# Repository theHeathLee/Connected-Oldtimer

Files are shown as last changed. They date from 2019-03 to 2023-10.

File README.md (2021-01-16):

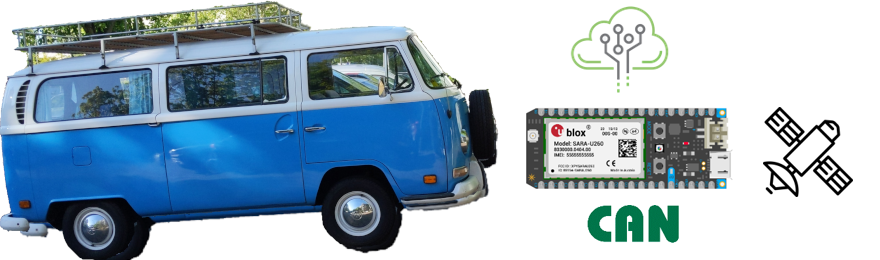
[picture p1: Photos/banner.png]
Connected oldtimer banner


# Connected-Oldtimer

The aim of this project to modernize my old Volkswagen T2 by adding sensors everywhere and make it part of the internet of things. This project is not vehicle specific and can be implimented in any pre OBD vehicle.

The goal here is first to make remote monitoring possible. Motion sensing for anti theft will be implemented as the vehicle does a lot of sitting. (my bicycle has x4 the ammount of kms per year on it as the bus). Additionaly the ability to remotely view levels (battery charge, fuel level etc..)

Alongside remote monitoring I have implmented an HMI using a 3.5" Display that fits in the dash area originally inteded for the RPM guage. This display shows the instantanious data such as speed, RPM, and Temperature.

A low speed CAN network is set up throughout the vehicle to easily add extra sensors.

Disclaimer: Still in the __developement phase__. V1 hardware has been created and software is still in heavy developement.

### Software used:
- Visual Studio Code w/ [Particle Workbench Extentsion](https://marketplace.visualstudio.com/items?itemName=particle.particle-vscode-pack)🤘
- Particle [Cloud](https://www.particle.io/device-cloud/) 
- [BusMaster](http://rbei-etas.github.io/busmaster/)

### Things implemented:

- 3G Connectivity and vehicle to [cloud](https://www.particle.io/device-cloud/) data transfer   
- Gps velocity and location tracking and display  
- CAN Bus Sensor Data
- Movement Sensor 
- 3D Printed Display mount ([Thingiverse](https://www.thingiverse.com/thing:4713912))

### Parts List:

- [Particle Electron](https://www.particle.io/cellular/)
- [Nextion 3.5" Display](https://www.itead.cc/nextion-nx4832t035.html)
- [Adafruit Ultimage GPS](https://www.adafruit.com/product/746)
- [Adafruit I2C FRAM](https://www.adafruit.com/product/1895)
- [Shock Sensor SW-420](https://components101.com/sensors/sw-420-vibration-sensor-module)
- [CAN Bus Tranceiver Module (TJA1051)](https://www.nxp.com/products/analog/interfaces/in-vehicle-network/can-transceiver-and-controllers/high-speed-can-transceiver:TJA1051)
- [CAN Bus Cable](https://www.conrad.de/de/p/busleitung-unitronic-bus-2-x-2-x-0-22-mm-violett-lapp-2170261-meterware-604030.html)
- PCB From this Repo
- [~~Fuel Flow Meter~~](https://www.conrad.com/p/bt-bio-tech-fch-m-pom-lc-ad-6-mm-low-flow-flowmeter-non-corrosive-liquids-water-diesel-oil-150392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)

# End Product

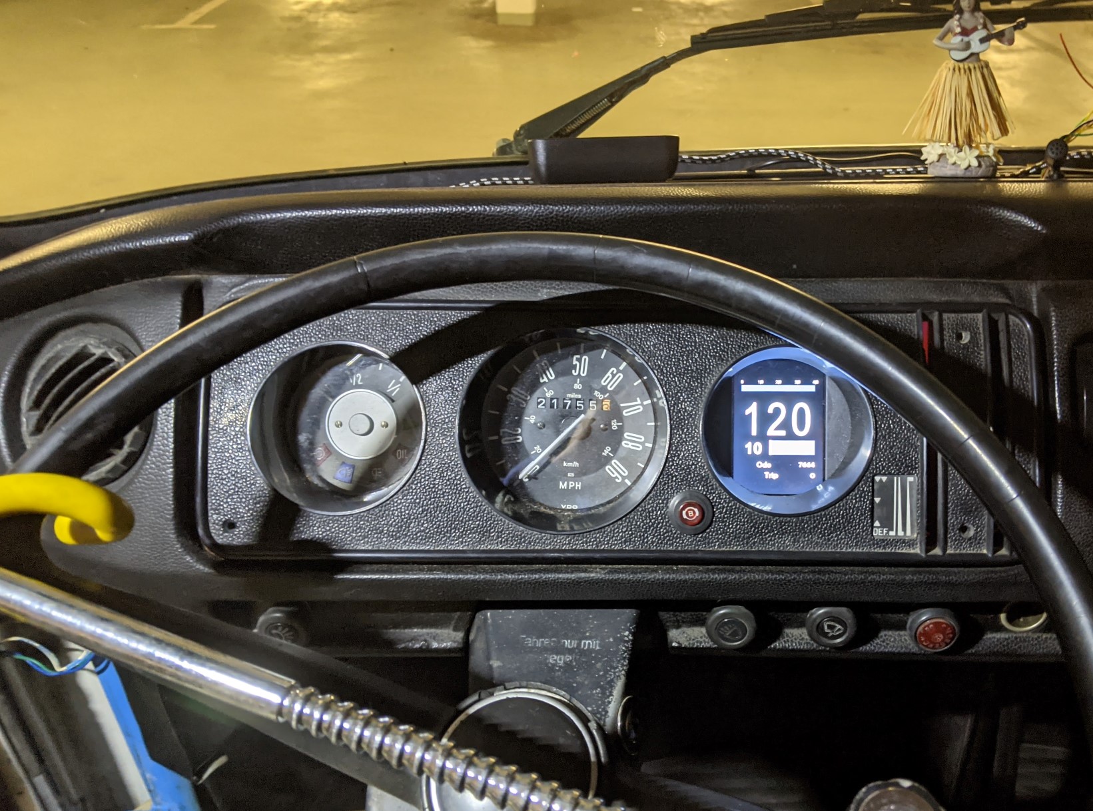
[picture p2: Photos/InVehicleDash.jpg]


# Hardware

[BOM Viewer](https://htmlpreview.github.io/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)

### Schematic

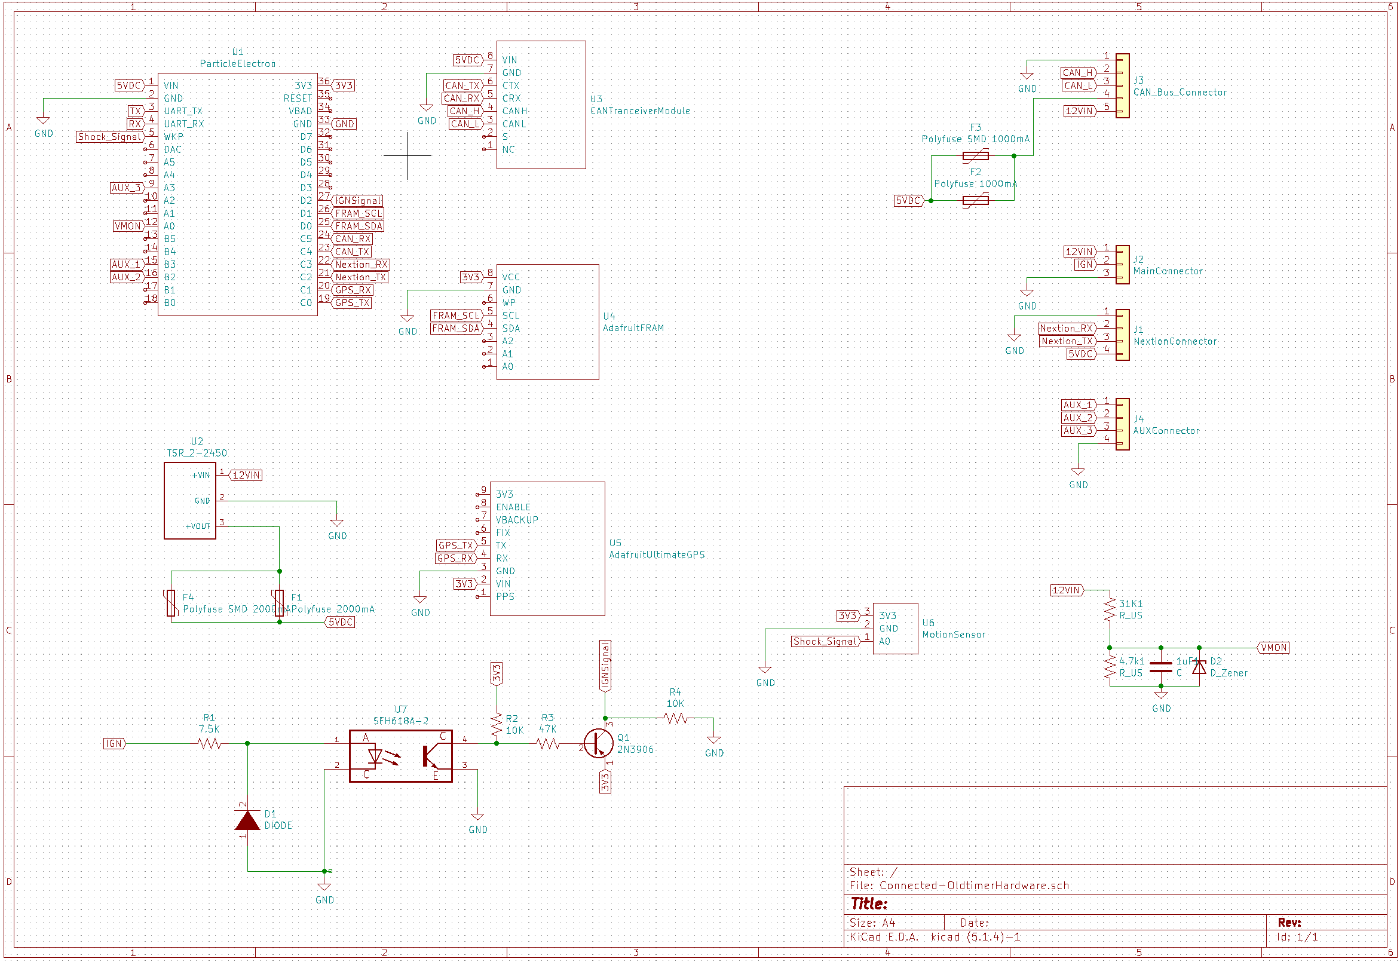
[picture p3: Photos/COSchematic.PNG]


### PCB

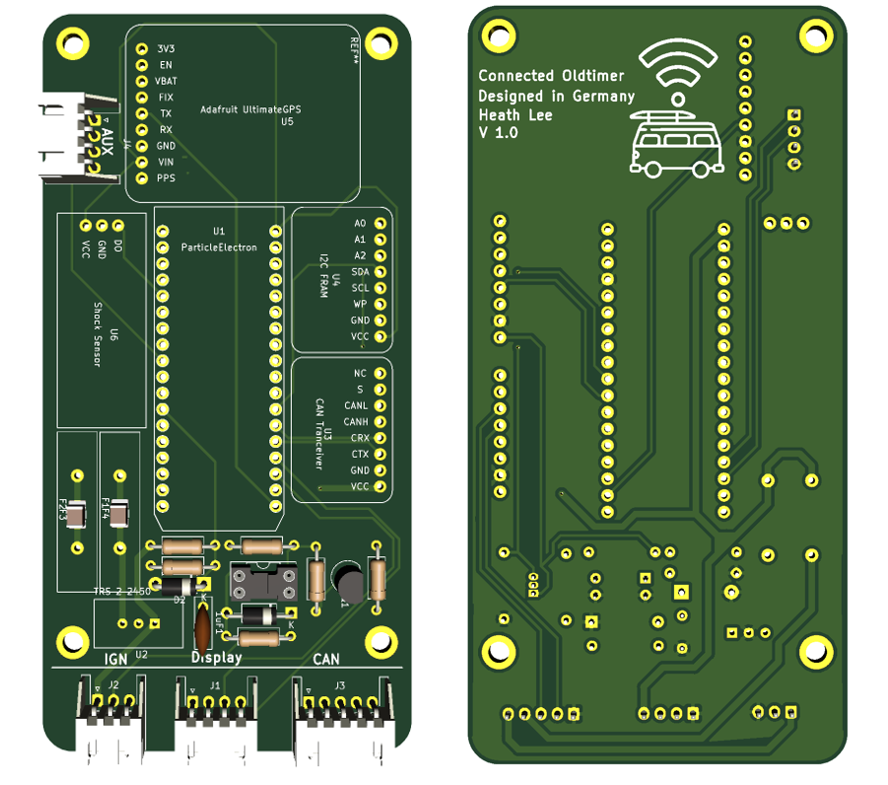
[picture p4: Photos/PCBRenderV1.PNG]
pcb


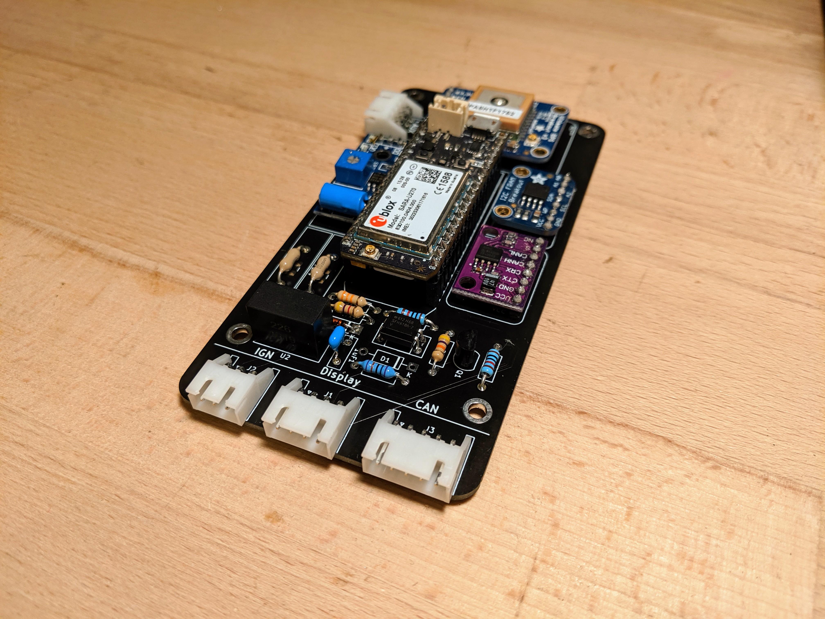
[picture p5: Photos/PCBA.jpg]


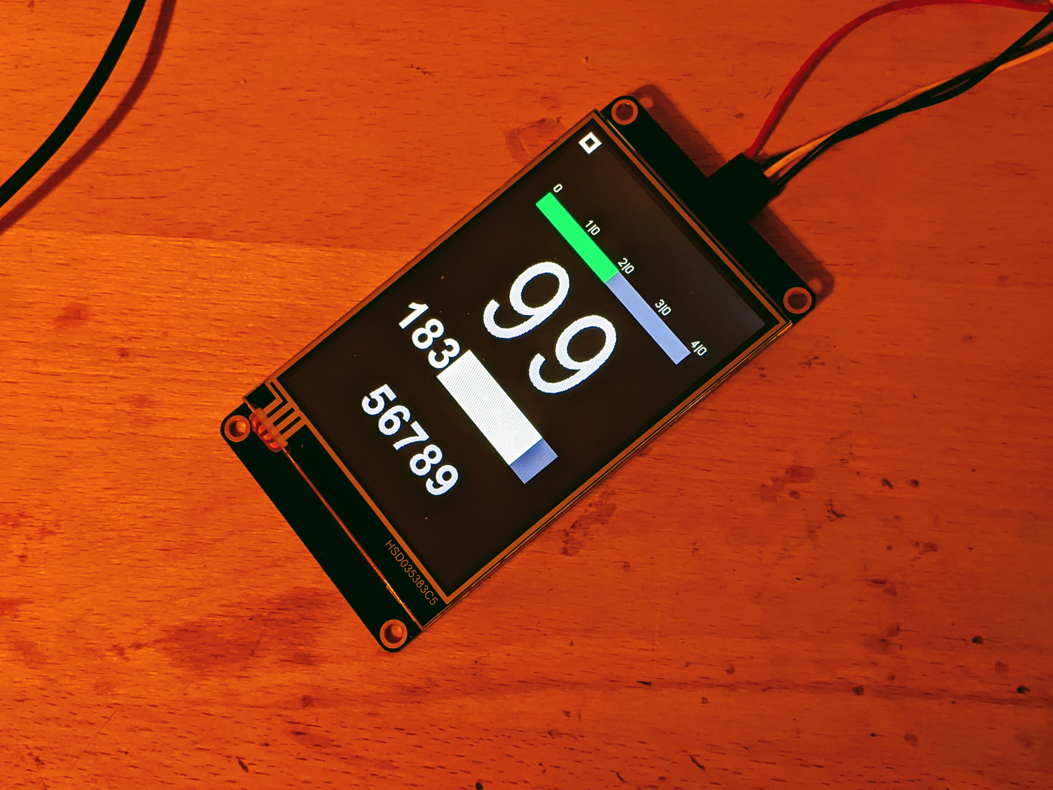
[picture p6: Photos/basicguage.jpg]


## 3D Printed Bracket

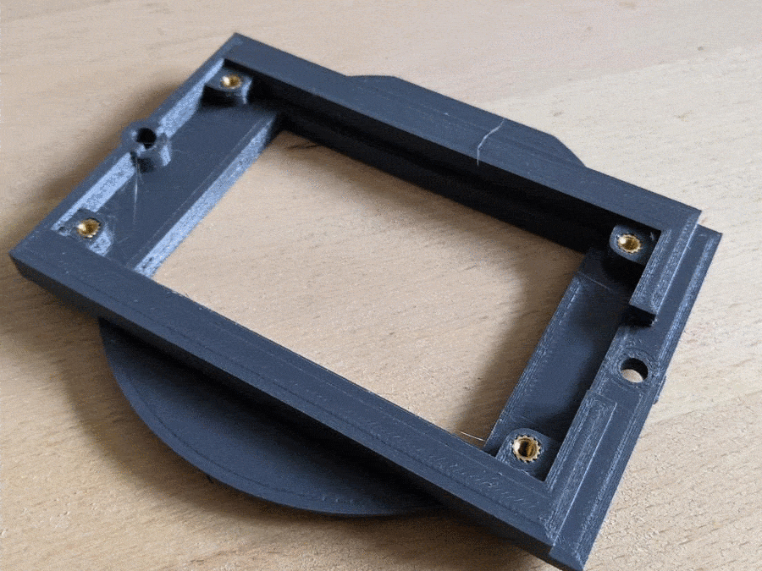
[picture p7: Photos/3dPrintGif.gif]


Art Credits:
[Freepik](https://www.flaticon.com/authors/freepik)

## CAN Matrix

| Value | ID |DLC | Byte Pos.|
| --- |:-----:|----:| --:|
| Temp (C) | 0x100 | 8 |0 |
| RPM | 0x200 | 8 |0, 1|
| Fuel Level | 0x300 | 8 |0 |
| Fuel Flow | 0x400 | 8 |0 |

## Nextion Component Values

| Component  | Value |
| --- |:-----:|
Speed (Kmh) | n0
Odometer (Km) | n1
Trip Counter (Km) | n3
CHT (C) | n2
RPM | va0

# References

## GPS

### NMEA Simulation
[SatGen](https://www.labsat.co.uk/index.php/de/free-gps-nmea-simulator-software) Windows software form LabSat used for playing NMEA files over virtual coms

[NMEAGen](https://nmeagen.org/) browser application for generating custom NMEA files

To create a GPS simulation, first create an NMEA file in NMEAGen. after generating a .nmea file, change the file extension to .txt. The file can now be played in the Serial Output tab of SatGen.

Any USB to TTL coverter can be connected to ports C0 & C1 (Serial5) of the Electron.

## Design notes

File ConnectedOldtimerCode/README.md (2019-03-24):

# ConnectedOldtimerCode

A Particle project named ConnectedOldtimerCode

## Welcome to your project!

Every new Particle project is composed of 3 important elements that you'll see have been created in your project directory for ConnectedOldtimerCode.

#### ```/src``` folder:  
This is the source folder that contains the firmware files for your project. It should *not* be renamed. 
Anything that is in this folder when you compile your project will be sent to our compile service and compiled into a firmware binary for the Particle device that you have targeted.

If your application contains multiple files, they should all be included in the `src` folder. If your firmware depends on Particle libraries, those dependencies are specified in the `project.properties` file referenced below.

#### ```.ino``` file:
This file is the firmware that will run as the primary application on your Particle device. It contains a `setup()` and `loop()` function, and can be written in Wiring or C/C++. For more information about using the Particle firmware API to create firmware for your Particle device, refer to the [Firmware Reference](https://docs.particle.io/reference/firmware/) section of the Particle documentation.

#### ```project.properties``` file:  
This is the file that specifies the name and version number of the libraries that your project depends on. Dependencies are added automatically to your `project.properties` file when you add a library to a project using the `particle library add` command in the CLI or add a library in the Desktop IDE.

## Adding additional files to your project

#### Projects with multiple sources
If you would like add additional files to your application, they should be added to the `/src` folder. All files in the `/src` folder will be sent to the Particle Cloud to produce a compiled binary.

#### Projects with external libraries
If your project includes a library that has not been registered in the Particle libraries system, you should create a new folder named `/lib/<libraryname>/src` under `/<project dir>` and add the `.h`, `.cpp` & `library.properties` files for your library there. Read the [Firmware Libraries guide](https://docs.particle.io/guide/tools-and-features/libraries/) for more details on how to develop libraries. Note that all contents of the `/lib` folder and subfolders will also be sent to the Cloud for compilation.

## Compiling your project

When you're ready to compile your project, make sure you have the correct Particle device target selected and run `particle compile <platform>` in the CLI or click the Compile button in the Desktop IDE. The following files in your project folder will be sent to the compile service:

- Everything in the `/src` folder, including your `.ino` application file
- The `project.properties` file for your project
- Any libraries stored under `lib/<libraryname>/src`

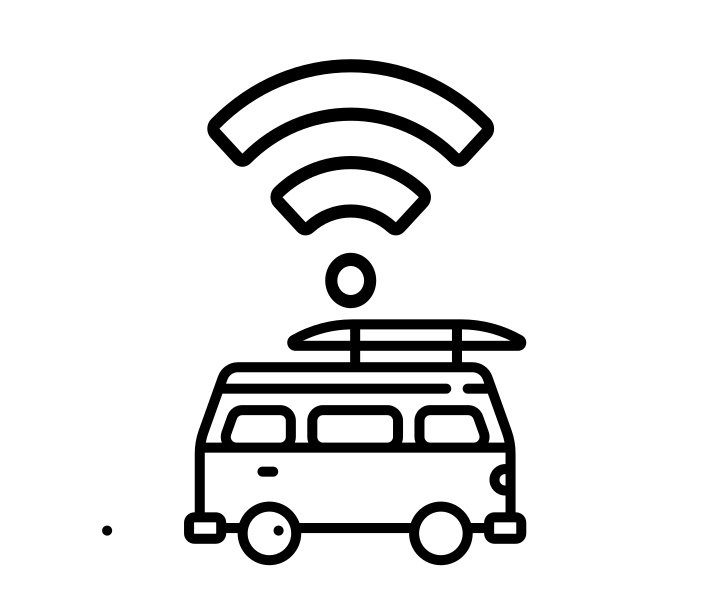
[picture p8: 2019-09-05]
Hardware/Connected-OldtimerHardware/.svg2shenzhen-cache/images/F.Cu_g201.png

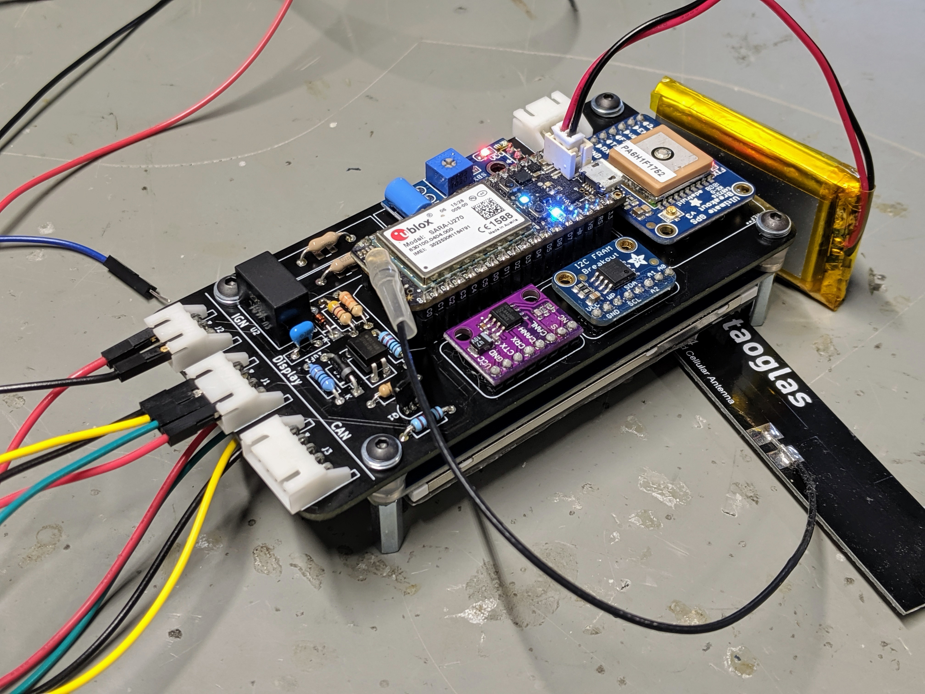
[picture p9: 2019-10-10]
Photos/PCBAWithScreenAndConnectors.jpg

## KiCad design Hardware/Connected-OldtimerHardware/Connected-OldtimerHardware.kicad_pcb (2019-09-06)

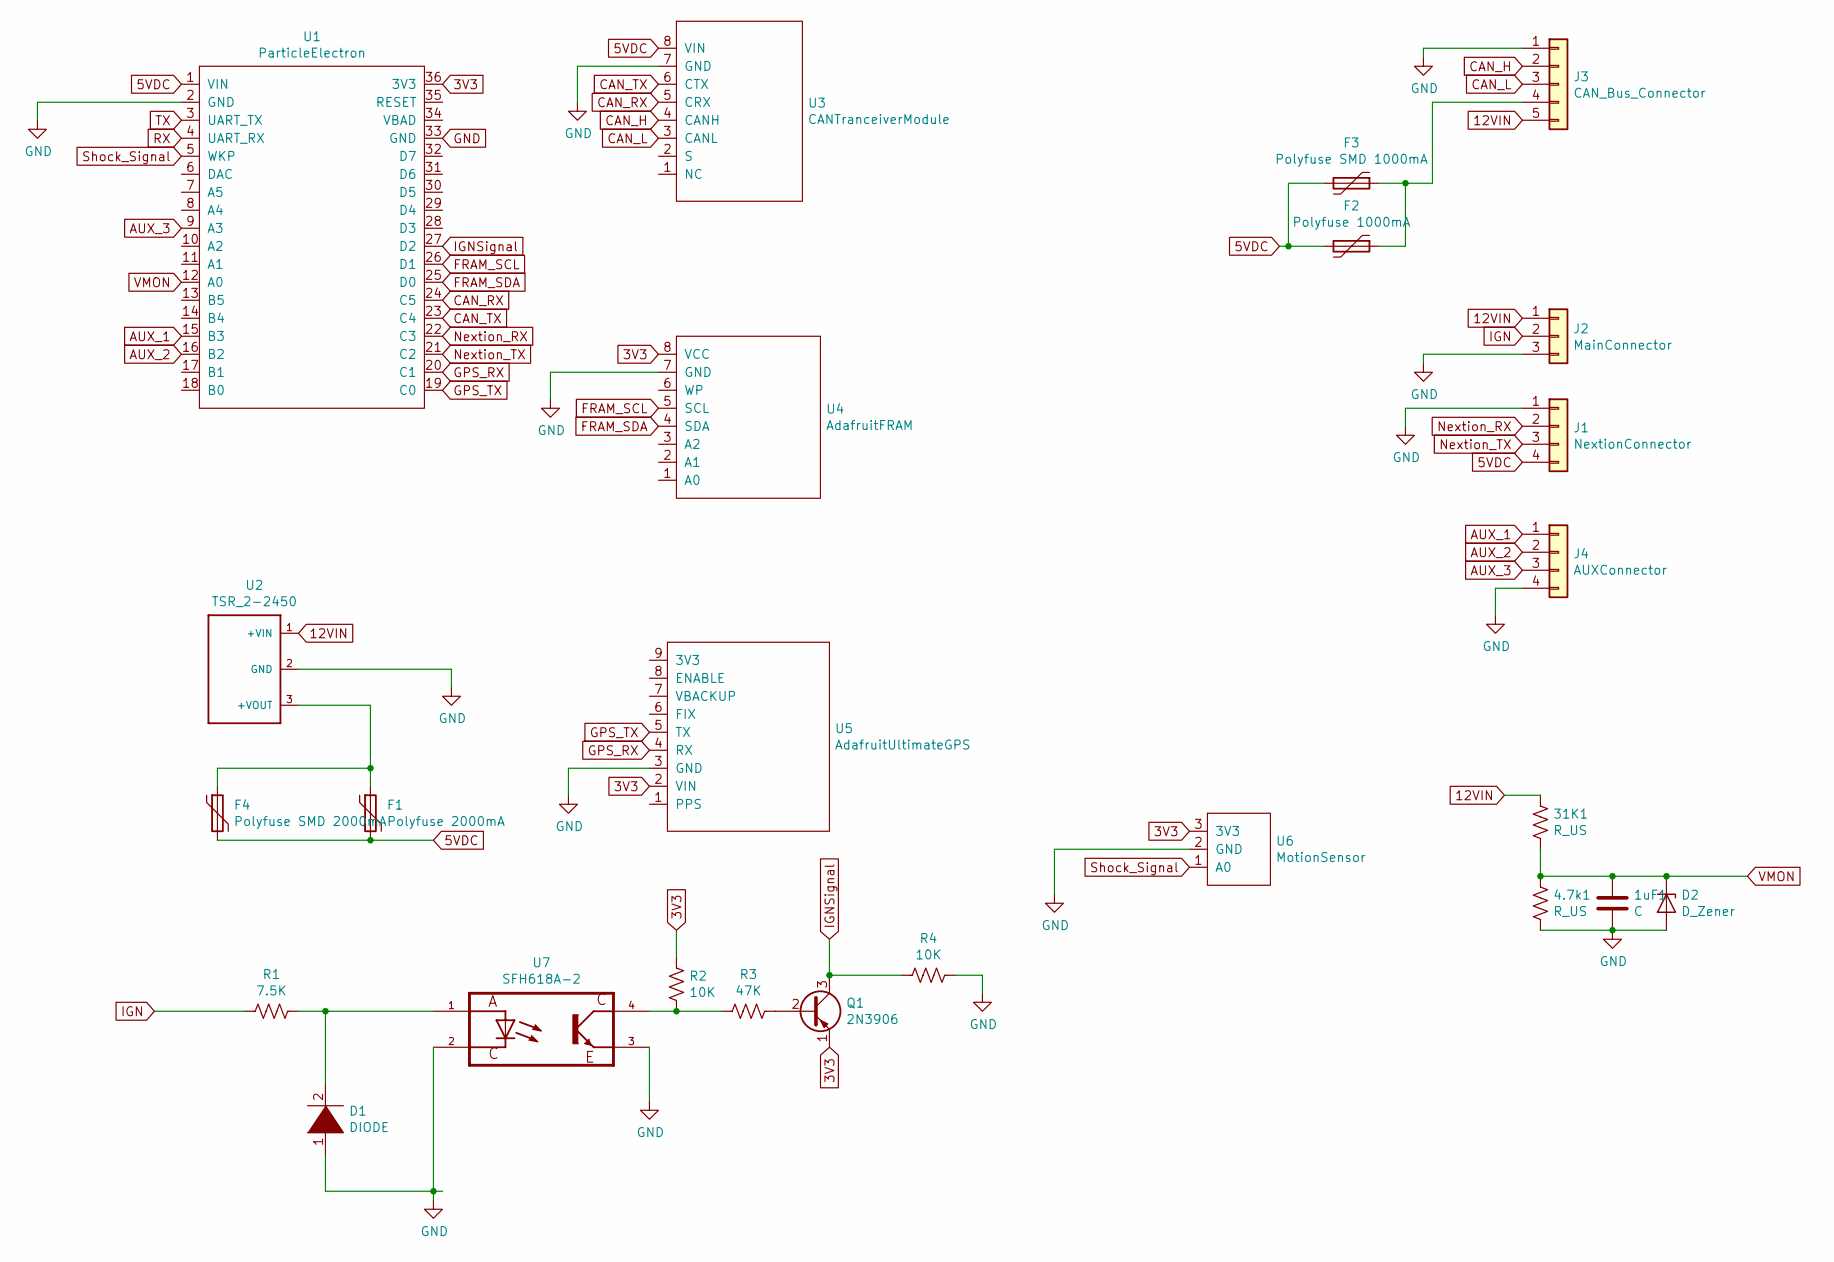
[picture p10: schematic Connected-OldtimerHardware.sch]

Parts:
1uF1: C; C_Disc_D8.0mm_W2.5mm_P5.00mm
4.7k1, 31K1: R_US; R_Axial_DIN0207_L6.3mm_D2.5mm_P10.16mm_Horizontal
D1: DIODE; D_A-405_P10.16mm_Horizontal
D2: D_Zener; D_DO-41_SOD81_P7.62mm_Horizontal
F1: Polyfuse 2000mA; Fuse_Littelfuse-LVR200
F2: Polyfuse 1000mA; Fuse_Littelfuse-LVR200
F3: Polyfuse SMD 1000mA; C_1210_3225Metric_Pad1.42x2.65mm_HandSolder
F4: Polyfuse SMD 2000mA; C_1210_3225Metric_Pad1.42x2.65mm_HandSolder
J1: NextionConnector; JST_XH_S04B-XH-A-1_1x04_P2.50mm_Horizontal
J2: MainConnector; JST_XH_S03B-XH-A-1_1x03_P2.50mm_Horizontal
J3: CAN_Bus_Connector; JST_XH_S05B-XH-A-1_1x05_P2.50mm_Horizontal
J4: AUXConnector; JST_XH_S04B-XH-A-1_1x04_P2.50mm_Horizontal
Q1: 2N3906; TO-92_Inline
R1: 7.5K; R_Axial_DIN0207_L6.3mm_D2.5mm_P10.16mm_Horizontal
R2, R4: 10K; R_Axial_DIN0207_L6.3mm_D2.5mm_P10.16mm_Horizontal
R3: 47K; R_Axial_DIN0207_L6.3mm_D2.5mm_P10.16mm_Horizontal
U1: ParticleElectron; electron
U2: TSR_2-2450; heathsTRS_2_2450
U3: CANTranceiverModule; CAN_Tranceiver_Module
U4: AdafruitFRAM; Adafruit_I2C_FRAM
U5: AdafruitUltimateGPS
U6: MotionSensor; ShockSensor
U7: SFH618A-2; DIP-4_W7.62mm_Socket

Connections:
3V3: Q1.1 (E), R2.1, U1.36 (3V3), U4.8 (VCC), U5.2 (VIN), U6.3 (3V3)
5VDC: F1.2, F2.2, F3.2, F4.2, J1.4, U1.1 (VIN), U3.8 (VIN)
12VIN: 31K1.1, J2.1, J3.5, U2.1 (+VIN)
AUX_1: J4.1, U1.15 (B3)
AUX_2: J4.2, U1.16 (B2)
AUX_3: J4.3, U1.9 (A3)
CAN_H: J3.2, U3.4 (CANH)
CAN_L: J3.3, U3.3 (CANL)
CAN_RX: U1.24 (C5), U3.5 (CRX)
CAN_TX: U1.23 (C4), U3.6 (CTX)
FRAM_SCL: U1.26 (D1), U4.5 (SCL)
FRAM_SDA: U1.25 (D0), U4.4 (SDA)
GND: 1uF1.2, 4.7k1.2, D1.1 (K), D2.2 (A), J1.1, J2.3, J3.1, J4.4, R4.1, U1.2 (GND), U1.33 (GND), U2.2 (GND), U3.7 (GND), U4.7 (GND), U5.3 (GND), U6.2 (GND), U7.2 (C), U7.3 (E)
GPS_RX: U1.20 (C1), U5.4 (RX)
GPS_TX: U1.19 (C0), U5.5 (TX)
IGN: J2.2, R1.2
IGNSignal: Q1.3 (C), R4.2, U1.27 (D2)
unnamed: D1.2 (A), R1.1, U7.1 (A)
unnamed: F1.1, F4.1, U2.3 (+VOUT)
unnamed: F2.1, F3.1, J3.4
unnamed: Q1.2 (B), R3.1
unnamed: R2.2, R3.2, U7.4 (CO)
Nextion_RX: J1.2, U1.22 (C3)
Nextion_TX: J1.3, U1.21 (C2)
RX: U1.4 (UART_RX)
Shock_Signal: U1.5 (WKP), U6.1 (A0)
TX: U1.3 (UART_TX)
VMON: 1uF1.1, 4.7k1.1, 31K1.2, D2.1 (K), U1.12 (A0)

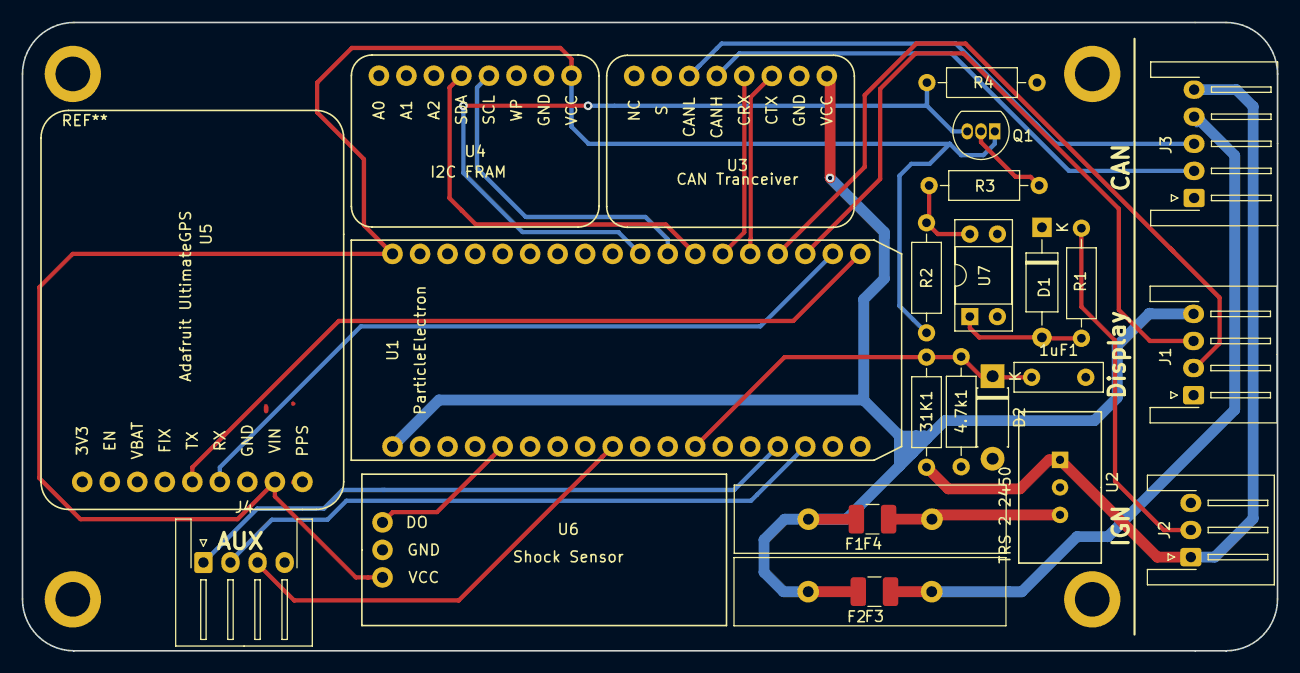
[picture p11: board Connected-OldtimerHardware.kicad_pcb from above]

Board: 2 copper layers, 115.8 x 58.0 mm, 25 parts (0 on the bottom side), 26 nets.

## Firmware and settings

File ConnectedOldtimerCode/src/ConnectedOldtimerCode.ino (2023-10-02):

SYSTEM_THREAD(ENABLED);
SYSTEM_MODE(AUTOMATIC);
#include "Serial4/Serial4.h"
#include "Serial5/Serial5.h"
#include "../lib/TinyGPS++/src/TinyGPS++.h"
#include "../lib/MB85RC256V-FRAM-RK/src/MB85RC256V-FRAM-RK.h"
#include "../lib/ITEADLIB_Nextion\src/ITEADLIB_Nextion.h"
//#include "../lib/ITEADLIB_Nextion\src\ITEADLIB_Nextion\Nextion.h"
#include <math.h>

#define earthRadiusKm 6371.0 // for use in haversine calculation 

uint8_t nextionSpeed = 255;
uint8_t fuelLevel, FuelFlow, fuelUsed, litersper100km, vacuum, vacuumefficiency = 0;
uint8_t fuelLevelold, FuelFlowold, fuelUsedold, litersper100kmold, vacuumold, vacuumefficiencyold, motorTemperatureold = 0;
uint8_t motorTemperature = 10;
uint8_t oilPressure, oilPressureOld = 0;
uint8_t setSpeedKmh = 1;
uint16_t motorRPM, motorRPMold = 0;
int demoConnectivityValue = 64;
static const uint32_t GPSBaud = 9600;
unsigned long Heartbeat_200mS_Start = millis();
unsigned long Heartbeat_1000mS_Start = millis();
unsigned long Heartbeat_2000mS_Start = millis();
double locationX1, locationX2, locationY1, locationY2, latestDistanceTraveled, odometerValue, pbBatteryVoltage;
double tripValue = 55;
int led = D7;
int activateLock = B2;
int activateUnlock = B3;
int pbBatVoltPin = A0;
int pwerDisplayEnable = B4;
int ignitionSignal = D2;
int GPSEnable = B5;
int pwr5VoltEnable = A1;
int shockSense = WKP;

//Nextion Object Defs
USARTSerial& nexSerial = Serial4;
NexButton b0 = NexButton(1, 2, "b0");
NexTouch *nex_listen_list[] = 
{
    &b0,
    NULL
};

//todo change to defien 
double batCalibrationMultiplier = 12.8151; //calculated excel todo c
double batCalibrationOffset = -9.9; // calculated excel

TinyGPSPlus gps;
CANChannel can(CAN_C4_C5);

//FRAM Stuff
MB85RC256V fram(Wire, 0);



void setup() {

  //particle variables
  Particle.variable("dummyValue", demoConnectivityValue);
  Particle.variable("PosLat", locationY2);
  Particle.variable("PosLon", locationX2);
  Particle.variable("PBBatVolt", pbBatteryVoltage);

  //particle functions
  Particle.function("LockDrs", lockDoors);
  Particle.function("UnlockDrs", UnlockDoors);
  Particle.function("deepSleep", activateDeepSleep);
  Particle.function("activate5v", activate5Volts);
  
  
  can.begin(250000); // initialize can at 250 kbs 
  Serial.begin(9600); //usb debugging
  Serial1.blockOnOverrun(true);
  Serial5.begin(GPSBaud); // uart for GPS
  Serial1.begin(GPSBaud); // 
  pinMode(led, OUTPUT);
  pinMode(activateLock, OUTPUT);
  pinMode(activateUnlock, OUTPUT);
  pinMode(pwerDisplayEnable, OUTPUT);
  pinMode(GPSEnable, OUTPUT);
  pinMode(pwr5VoltEnable, OUTPUT);
  pinMode(ignitionSignal, INPUT);
  pinMode(shockSense, INPUT);
  Serial.println("contoroller running");

  digitalWrite(GPSEnable, HIGH);
  //System.sleep(SLEEP_MODE_DEEP);
  

  //FRAM Setup stuff
  fram.begin();
  readFromFRAM(); // pulls FRAM values for last odo, fuel, and gps into memory

  //Nextion
  nexInit(250000);
  
  b0.attachPop(b0PopCallback, &b0);

}


void loop() {

if (millis() >= Heartbeat_200mS_Start + 200) {

    //all funtions to be run every 200mS
    //canSend();
    updateDisplay();
    //canReceive(); 
    Heartbeat_200mS_Start = millis(); //reset timer
  }

if (millis() >= Heartbeat_1000mS_Start + 1000) {

    //all funtions to be run every second
    statusLED();
    storeToFRAM(); //Todo - comment this back in when there is a change compare
    //serialLogger();
    
    Heartbeat_1000mS_Start = millis(); //reset timer
  }

if (millis() >= Heartbeat_2000mS_Start + 2000) {

   updateOdometer(); 
   pbBatteryVoltage = double((analogRead(pbBatVoltPin)*batCalibrationMultiplier)/1000)+batCalibrationOffset;
   //Serial.println(pbBatteryVoltage);

  Heartbeat_2000mS_Start = millis();
}

//funtions being executed as fast as possible
ignitionSignalCheck();
getGpsInfo();
//tripResetCheck(); bug: this is causing a big delay
//shockSensorCheck();
canReceive(); 
nexLoop(nex_listen_list);




}

void canReceive(){
  
  CANMessage message;
  can.receive(message);
  switch (message.id)
  {
  case 0x100:
    motorTemperature = message.data[0];
    break;
  case 0x200:
    motorRPM =  message.data[0]| message.data[1]<<8;
    break;
  case 0x300:
    fuelLevel = message.data[0];
    break;
  case 0xB600:
    //maybe add some sensors 
    break;
  case 0xB601:
    //motorRPM = message.data[0] << 8 | message.data[1];
   // fuelLevel = message.data[7];
    break;
  case 0x400:
    FuelFlow = message.data[0];
    fuelUsed = message.data[1];
    litersper100km = message.data[2];
    fuelLevel = message.data[3];
    vacuum = message.data[4];
    vacuumefficiency = message.data[5];
    break;
  default:
    break;
  }

  
}  

void canSend(){

  CANMessage messageOut;
  messageOut.id = 0x555;
  messageOut.len = 3;
  messageOut.data[0] = 0xC0;
  messageOut.data[1] = 0xff;
  messageOut.data[2] = 0xEE;
  can.transmit(messageOut); //actually transmits the message 

}  



void statusLED(){
  
    digitalWrite(led, !digitalRead(led));
}  

void getGpsInfo() {
    while (Serial5.available())
      gps.encode(Serial5.read());

    
    //read speed directly 
    if (gps.location.isValid()) {
      nextionSpeed = (uint8_t) ( gps.speed.kmph() + 0.5 - (gps.speed.kmph()<0) ); // gets speed, rounds it and converts to an integer
    }
    else {
      //Serial.println("GPS Location invalid");
    }

} 

void updateOdometer() {

    // calculate dynamic distance traveled
    if (gps.location.isValid()) { //use this instead of isValid to avoid calculation redundancy
      locationX1 = locationX2; 
      locationX2 = gps.location.lng(); 
      locationY1 = locationY2; 
      locationY2 = gps.location.lat(); 


      latestDistanceTraveled =  distanceEarth( locationY1, locationX1, locationY2 ,locationX2 );
      
      // filter out impossible  distances but but allow no signal events like tunnels
      if (latestDistanceTraveled < 20.0 && (gps.speed.kmph() > 1.0)) {
        odometerValue = odometerValue + latestDistanceTraveled;
        tripValue = tripValue + latestDistanceTraveled;
      }
      Serial.print ("Speed = ");
      Serial.print (gps.speed.kmph());
      Serial.print ("  x1 = ");
      Serial.print (locationX1);
      Serial.print (" x2 = ");
      Serial.print (locationX2, 6);
      Serial.print ("   y1 = ");
      Serial.print (locationY1);
      Serial.print (" y2 = ");
      Serial.print (locationY2, 6);
      Serial.print ("   Latest Distance=");
      Serial.print (latestDistanceTraveled, 6);
      Serial.print ("   Odometer=");
      Serial.print (odometerValue, 6);
      Serial.print ("  GPS accuracy=");
      Serial.print (gps.hdop.value());
      Serial.println();
    }
}

void updateDisplay() {


  // sends data to display
  nexSerial.printf("SpeedKmh.val=");
  nexSerial.print(nextionSpeed);
  // next 3 writes must be made for the Nextion to accept the update
  nextionTerminatMessage();

  // updates odometer value
  nexSerial.printf("n1.val=");
  nexSerial.print((uint32_t)((odometerValue + 0.5 - (odometerValue<0)) * 0.621371192 ));
  nextionTerminatMessage();


  //updates temperature value
  if (motorTemperature != motorTemperatureold)
  {
    nexSerial.printf("n2.val=");
    nexSerial.print(motorTemperature);
    nextionTerminatMessage();
  }
  motorTemperatureold = motorTemperature;
  Serial.print(motorTemperature);

  //updates RPM value
  if (motorRPM != motorRPMold)
  {
    nexSerial.printf("va0.val=");
    nexSerial.print(motorRPM);
    nextionTerminatMessage();
  }
  motorRPMold = motorRPM;
  Serial.println(motorRPM);

  //updates trip value
  nexSerial.printf("n3.val=");
  nexSerial.print((uint32_t)((tripValue + 0.5 - (tripValue<0)) * 0.621371192 ));
  nextionTerminatMessage(); 

  nexSerial.printf("n4.val=");
  nexSerial.print(Time.hour());
  nextionTerminatMessage(); 
  nexSerial.printf("n5.val=");
  nexSerial.print(Time.minute());
  nextionTerminatMessage(); 

  nexSerial.printf("n7.val=");
  nexSerial.print(pbBatteryVoltage);
  nextionTerminatMessage(); 
  nexSerial.printf("n6.val=");
  nexSerial.print(pbBatteryVoltage);
  nextionTerminatMessage(); 

  //update oil pressure
  if (oilPressure != oilPressureOld)
  {
    nexSerial.printf("OilPressure.val=");
    nexSerial.print(oilPressure);
    nextionTerminatMessage(); 
  }
  oilPressureOld = oilPressure;

  //update fuelLevel
  if (fuelLevel != fuelLevelold)
  {
    nexSerial.printf("fuellevel.val=");
    nexSerial.print(fuelLevel);
    nextionTerminatMessage(); 
  }
  fuelLevelold = fuelLevel;

  //update FuelFlow
  if (fuelLevel != fuelLevelold)
  {
    nexSerial.printf("Flow.val=");
    nexSerial.print(FuelFlow);
    nextionTerminatMessage(); 
  }
  fuelLevelold = fuelLevel;

  //update fuelUsed
  if (fuelUsed != fuelLevelold)
  {
    nexSerial.printf("Usage.val=");
    nexSerial.print(fuelUsed);
    nextionTerminatMessage(); 
  }
  fuelUsedold = fuelLevel;

  //update litersper100km
  if (litersper100km != litersper100kmold)
  {
    nexSerial.printf("literper100.val=");
    nexSerial.print(litersper100km);
    nextionTerminatMessage(); 
  }
  litersper100kmold = litersper100km;

  //update vacuum
  if (vacuum != vacuumold)
  {
    nexSerial.printf("vacuum.val=");
    nexSerial.print(vacuum);
    nextionTerminatMessage(); 
  }
  vacuumold = vacuum;

  //update ovacuumefficiency
  if (vacuumefficiency != vacuumefficiencyold)
  {
    nexSerial.printf("vacuumeffic.val=");
    nexSerial.print(vacuumefficiency);
    nextionTerminatMessage();
  }
  vacuumefficiencyold = vacuumefficiency; 
}

//run at startup
void readFromFRAM () {
  fram.get(0, odometerValue);// 8 bytes
  fram.get(8, fuelLevel);// 1 byte
  fram.get(9, locationX2);// 8 bytes
  fram.get(17, locationY2);// 8 bytes
  fram.get(25, tripValue);// 8 bytes
}


// stores data to FRAM chip every 5 seconds
void storeToFRAM (){

  //fram.writeData(0, (uint8_t *)&odometerValue, sizeof(odometerValue));
  fram.put(0, odometerValue);// 8 bytes
  fram.put(8, fuelLevel);// 1 byte
  fram.put(9, locationX2);// 8 bytes
  fram.put(17, locationY2);// 8 bytes
  fram.put(25, tripValue);// 8 bytes

}

void serialLogger (){
  Serial.print (" odometer:  ");
  Serial.println(odometerValue);
  Serial.print (" fuel:  ");
  Serial.print(fuelLevel);
  Serial.print(" NextionSpeed= ");
  Serial.print(nextionSpeed);
}

double distanceEarth(double lat1d, double lon1d, double lat2d, double lon2d) {
  double lat1r, lon1r, lat2r, lon2r, u, v;
  lat1r = deg2rad(lat1d);
  lon1r = deg2rad(lon1d);
  lat2r = deg2rad(lat2d);
  lon2r = deg2rad(lon2d);
  u = sin((lat2r - lat1r)/2);
  v = sin((lon2r - lon1r)/2);
  return 2.0 * earthRadiusKm * asin(sqrt(u * u + cos(lat1r) * cos(lat2r) * v * v));
}

double deg2rad(double deg) {
  return (deg * 3.1415926536 / 180);
}


void nextionTerminatMessage(){
  nexSerial.write(0xff);
  nexSerial.write(0xff);
  nexSerial.write(0xff);
}

int lockDoors(String args){
  digitalWrite(activateLock, LOW);
  digitalWrite(activateUnlock, HIGH);
  Serial.println("door lock command received");
  return 1;
}

int UnlockDoors(String args){
  digitalWrite(activateUnlock, LOW);
  digitalWrite(activateLock, HIGH);
  Serial.println("door unlock command received");
  return 1;
}

void ignitionSignalCheck(){
  if (digitalRead(ignitionSignal) == HIGH){
    digitalWrite(pwerDisplayEnable, HIGH);
    digitalWrite(pwr5VoltEnable, HIGH);
  }
  else
  {
    digitalWrite(pwerDisplayEnable, LOW);
    digitalWrite(pwr5VoltEnable, LOW);
  }
  
}

void shockSensorCheck(){
    if(digitalRead(shockSense)== HIGH){
      Serial.println("MOVEMENT Detected!!!");
    }
}

int activateDeepSleep(String args){
  //System.sleep(SLEEP_MODE_DEEP);
  SystemSleepConfiguration config;
  config.mode(SystemSleepMode::HIBERNATE)
        .gpio(WKP, RISING)
        .duration(60s);
  SystemSleepResult result = System.sleep(config);
  return 1;
}


int activate5Volts(String args){
digitalWrite(pwr5VoltEnable, atoi(args));
  return atoi(args);
}


void b0PopCallback(void *ptr)
{
  tripValue = 0;
}

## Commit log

2019-03-27 added can bus receive function
2019-05-04 fixed GPS Speed read
    changed data type to a double
    [ConnectedOldtimerCode.ino]
2019-05-04 fixed speed update
    nextion speed has to be uint8_t
    [ConnectedOldtimerCode.ino]
2019-05-14 moved status LED into its own function
2019-05-14 Thanos snaps his fingers
    [ConnectedOldtimerCode.ino]
2019-05-21 fixed status led timing
    [ConnectedOldtimerCode.ino]
2019-07-08 switched libraries
2019-07-09 I2C Fram Sign of life
2019-07-10 quick fix CAN pins
    [ConnectedOldtimerCode.ino]
2019-07-10 attempting to use timers
2019-08-27 Started Hardware KiCAD Project
    [Connected-OldtimerHardware.kicad_pcb, Connected-OldtimerHardware.sch]
2019-08-27 added electron footprint
    [Connected-OldtimerHardware.kicad_pcb]
2019-08-28 added modules
    [Connected-OldtimerHardware.sch]
2019-09-02 changed can bus to custom module
    [Connected-OldtimerHardware.sch]
2019-09-02 changed electron to module
    [Connected-OldtimerHardware.sch]
2019-09-02 rest of module conversions
    [Connected-OldtimerHardware.sch]
2019-09-02 added 12 to 5 V Switching Regulator
    [Connected-OldtimerHardware.sch]
2019-09-02 added opto coupler
    [Connected-OldtimerHardware.sch]
2019-09-02 completed Ignition Opto Coupler
    [Connected-OldtimerHardware.sch]
2019-09-03 changed GPS to 3.3V Power
    [Connected-OldtimerHardware.sch]
2019-09-03 completed footprints
    [_saved_Connected-OldtimerHardware.sch]
2019-09-03 reordered can module pins
    [Connected-OldtimerHardware.sch, _saved_Connected-OldtimerHardware.sch]
2019-09-03 renamed pinflags to purposes
    [Connected-OldtimerHardware.sch]
2019-09-03 added polyfuses
    [Connected-OldtimerHardware.sch]
2019-09-03 redid Regulator Footprint
    [Connected-OldtimerHardware.sch]
2019-09-04 layout v1
    [Connected-OldtimerHardware.kicad_pcb, Connected-OldtimerHardware.sch, _saved_Connected-OldtimerHardware.sch]
2019-09-04 all connections except ground and 5v
    [Connected-OldtimerHardware.kicad_pcb, Connected-OldtimerHardware.sch, _saved_Connected-OldtimerHardware.sch]
2019-09-04 completed tracks
    [Connected-OldtimerHardware.kicad_pcb, Connected-OldtimerHardware.sch]
2019-09-04 minor changes
    [Connected-OldtimerHardware.kicad_pcb]
2019-09-05 changed up connectors
    [Connected-OldtimerHardware.kicad_pcb, Connected-OldtimerHardware.sch]
2019-09-05 camper silkscreen
    [Connected-OldtimerHardware.kicad_pcb, drawing.kicad_pcb]
2019-09-05 made dem tracks thick
    [Connected-OldtimerHardware.kicad_pcb]
2019-09-05 switched to horizontal plugs
    [Connected-OldtimerHardware.kicad_pcb, Connected-OldtimerHardware.sch]
2019-09-06 Generated Gerbers
    [Connected-OldtimerHardware-B.Cu.gbr, Connected-OldtimerHardware-B.Mask.gbr, Connected-OldtimerHardware-B.SilkS.gbr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]
2019-09-09 created BOM
2019-09-24 reverted back !timers
2019-10-04 added speed prints
2019-10-09 timer reset was missing
    [ConnectedOldtimerCode.ino]
2019-10-11 more print statements
2019-10-16 hdop value rather than average filter
2019-10-18 fixed Km Jumping on startup
    [ConnectedOldtimerCode.ino]
2019-10-18 manually added current hmi file
2020-04-13 add schematic to readme
2020-04-13 fix RPM CAN read
    [ConnectedOldtimerCode.ino]
2020-04-21 add battery voltage monitor
2020-04-21 added Display power toggle and shock sense signal
2020-04-23 added code for all hardware power management additions
2020-12-16 fix reset trip function and add line return to nextion
    [ConnectedOldtimerCode.ino]
2020-12-16 fixed FRAM setter and beautify
    [ConnectedOldtimerCode.ino]
